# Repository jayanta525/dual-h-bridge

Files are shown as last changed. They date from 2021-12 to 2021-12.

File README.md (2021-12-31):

### Personal Project

2021

# Dual H Bridge Controller with N-CH MOSFETS

- IRF3205 N Channel MOSFET
- IR2104 MOSFET Driver
- ATMega328P-AU PWM Generator

#### Made for Dual 250W Brushed wheelchair motor
#### Schematics: https://jayanta525.gitlab.io/dual-h-bridge/sch/
#### Schematics: https://jayanta525.github.io/dual-h-bridge/sch/

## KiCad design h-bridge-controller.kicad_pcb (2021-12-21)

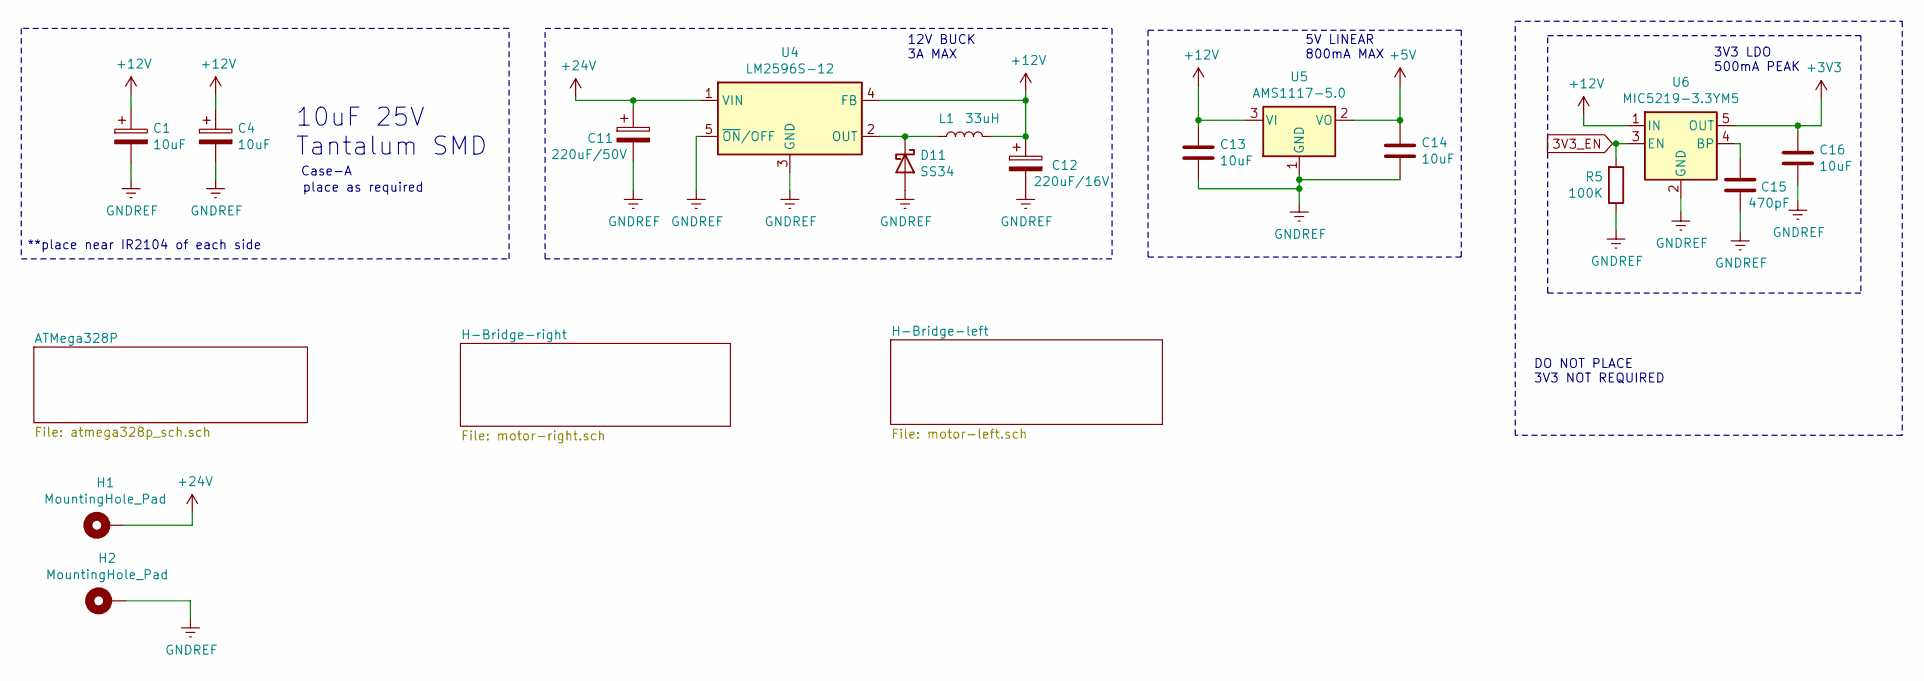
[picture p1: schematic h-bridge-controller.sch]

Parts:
C1, C4: 10uF; CP_EIA-3216-18_Kemet-A
C11: 220uF/50V; CP_Elec_10x10.5
C12: 220uF/16V; CP_Elec_6.3x7.7
C13, C14, C16: 10uF; C_0805_2012Metric
C15: 470pF; C_0805_2012Metric
D11: SS34; D_SMA
H1, H2: MountingHole_Pad; MountingHole_2.2mm_M2_Pad_Via
L1: 33uH; L_12x12mm_H4.5mm
R5: 100K; R_0805_2012Metric
U4: LM2596S-12; TO-263-5_TabPin3
U5: AMS1117-5.0; SOT-223-3_TabPin2
U6: MIC5219-3.3YM5; SOT-23-5

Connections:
3V3_EN: R5.2, U6.3 (EN); also elsewhere on the board
+3V3: C16.1, U6.5 (OUT)
+5V: C14.1, U5.2 (VO); also elsewhere on the board
+12V: C1.1, C4.1, C12.1, C13.1, L1.2, U4.4 (FB), U5.3 (VI), U6.1 (IN); also elsewhere on the board
+24V: C11.1, H1.1, U4.1 (VIN); also elsewhere on the board
GNDREF: C1.2, C4.2, C11.2, C12.2, C13.2, C14.2, C15.2, C16.2, D11.2 (A), H2.1, R5.1, U4.3 (GND), U4.5 (~ON~/OFF), U5.1 (GND), U6.2 (GND); also elsewhere on the board
unnamed: C15.1, U6.4 (BP)
unnamed: D11.1 (K), L1.1, U4.2 (OUT)

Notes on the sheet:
10uF 25V Tantalum SMD
Case-A
place as required
12V BUCK 3A MAX
5V LINEAR 800mA MAX
3V3 LDO 500mA PEAK
**place near IR2104 of each side
DO NOT PLACE 3V3 NOT REQUIRED

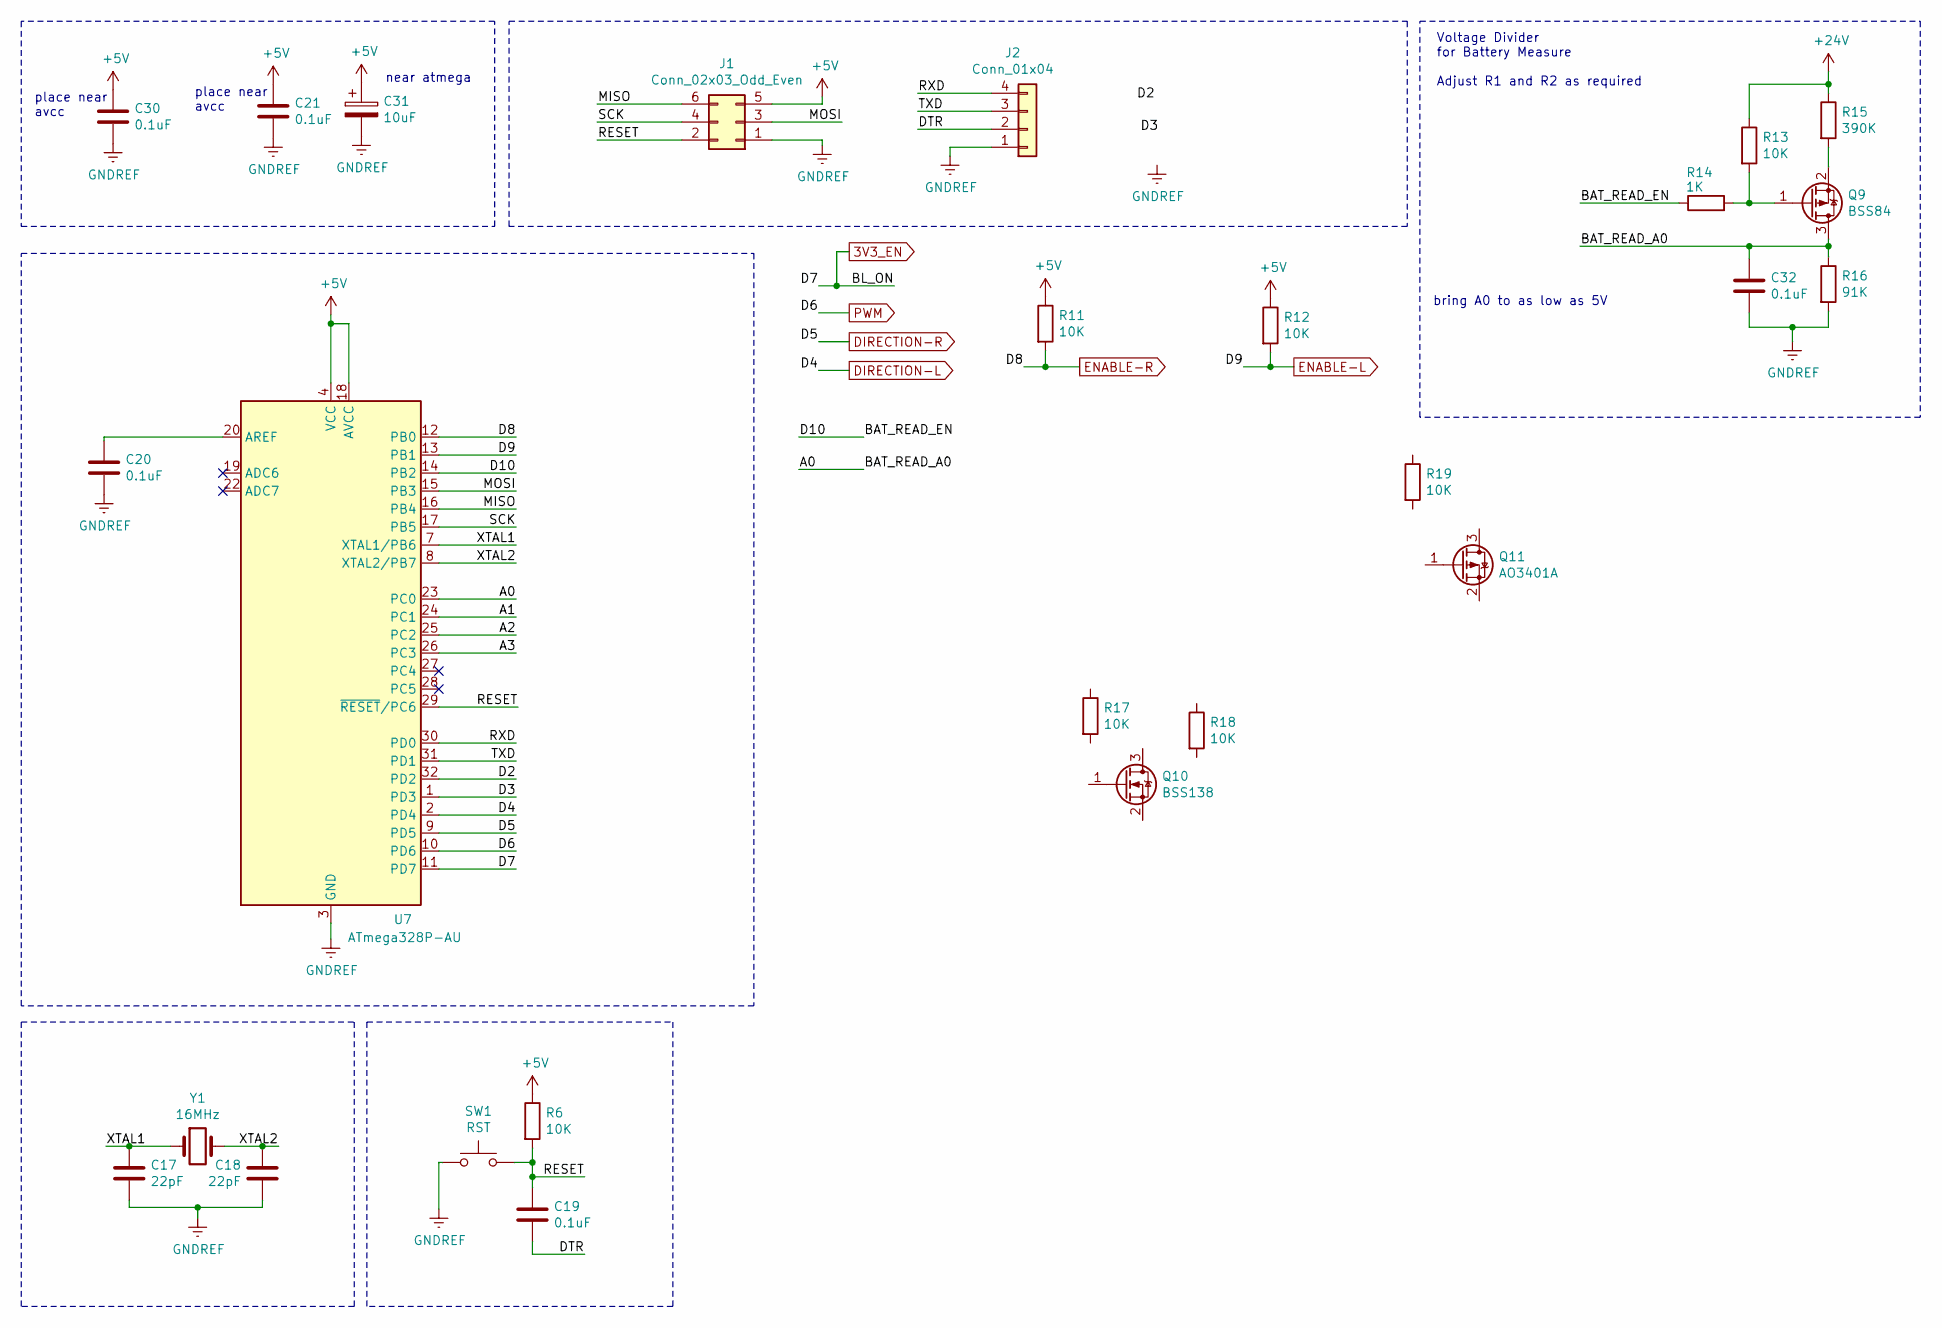
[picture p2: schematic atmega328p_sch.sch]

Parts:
C17, C18: 22pF; C_0805_2012Metric
C19, C20, C21, C30, C32: 0.1uF; C_0805_2012Metric
C31: 10uF; CP_EIA-3216-18_Kemet-A
J1: Conn_02x03_Odd_Even; PinHeader_2x03_P2.54mm_Vertical
J2: Conn_01x04; PinHeader_1x04_P2.54mm_Vertical
Q9: BSS84; SOT-23
Q10: BSS138; SOT-23
Q11: AO3401A; SOT-23
R6, R11, R12, R13, R17, R18, R19: 10K; R_0805_2012Metric
R14: 1K; R_0805_2012Metric
R15: 390K; R_0805_2012Metric
R16: 91K; R_0805_2012Metric
SW1: RST; SW_SPST_TL3342
U7: ATmega328P-AU; TQFP-32_7x7mm_P0.8mm
Y1: 16MHz; Crystal_SMD_HC49-SD

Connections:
3V3_EN: U7.11 (PD7); also elsewhere on the board
+5V: C21.1, C30.1, C31.1, J1.5, R6.1, R11.1, R12.1, U7.4 (VCC), U7.6 (VCC), U7.18 (AVCC); also elsewhere on the board
+24V: R13.1, R15.1; also elsewhere on the board
/ATMega328P/A0: C32.1, Q9.3 (D), R16.1, U7.23 (PC0)
/ATMega328P/A1: U7.24 (PC1)
/ATMega328P/A2: U7.25 (PC2)
/ATMega328P/A3: U7.26 (PC3)
/ATMega328P/BAT_READ_EN: R14.1, U7.14 (PB2)
/ATMega328P/D2: U7.32 (PD2)
/ATMega328P/D3: U7.1 (PD3)
/ATMega328P/DTR: C19.2, J2.2
/ATMega328P/MISO: J1.6, U7.16 (PB4)
/ATMega328P/MOSI: J1.3, U7.15 (PB3)
/ATMega328P/RESET: C19.1, J1.2, R6.2, SW1.2, U7.29 (~RESET~/PC6)
/ATMega328P/RXD: J2.4, U7.30 (PD0)
/ATMega328P/SCK: J1.4, U7.17 (PB5)
/ATMega328P/TXD: J2.3, U7.31 (PD1)
/ATMega328P/XTAL1: C17.1, U7.7 (XTAL1/PB6), Y1.1
/ATMega328P/XTAL2: C18.1, U7.8 (XTAL2/PB7), Y1.2
DIRECTION-L: U7.2 (PD4); also elsewhere on the board
DIRECTION-R: U7.9 (PD5); also elsewhere on the board
ENABLE-L: R12.2, U7.13 (PB1); also elsewhere on the board
ENABLE-R: R11.2, U7.12 (PB0); also elsewhere on the board
GNDREF: C17.2, C18.2, C20.2, C21.2, C30.2, C31.2, C32.2, J1.1, J2.1, R16.2, SW1.1, U7.3 (GND), U7.5 (GND), U7.21 (GND); also elsewhere on the board
unnamed: C20.1, U7.20 (AREF)
unnamed: Q9.1 (G), R13.2, R14.2
unnamed: Q9.2 (S), R15.2
PWM: U7.10 (PD6); also elsewhere on the board

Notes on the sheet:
place near avcc
near atmega
Voltage Divider for Battery Measure Adjust R1 and R2 as required
bring A0 to as low as 5V

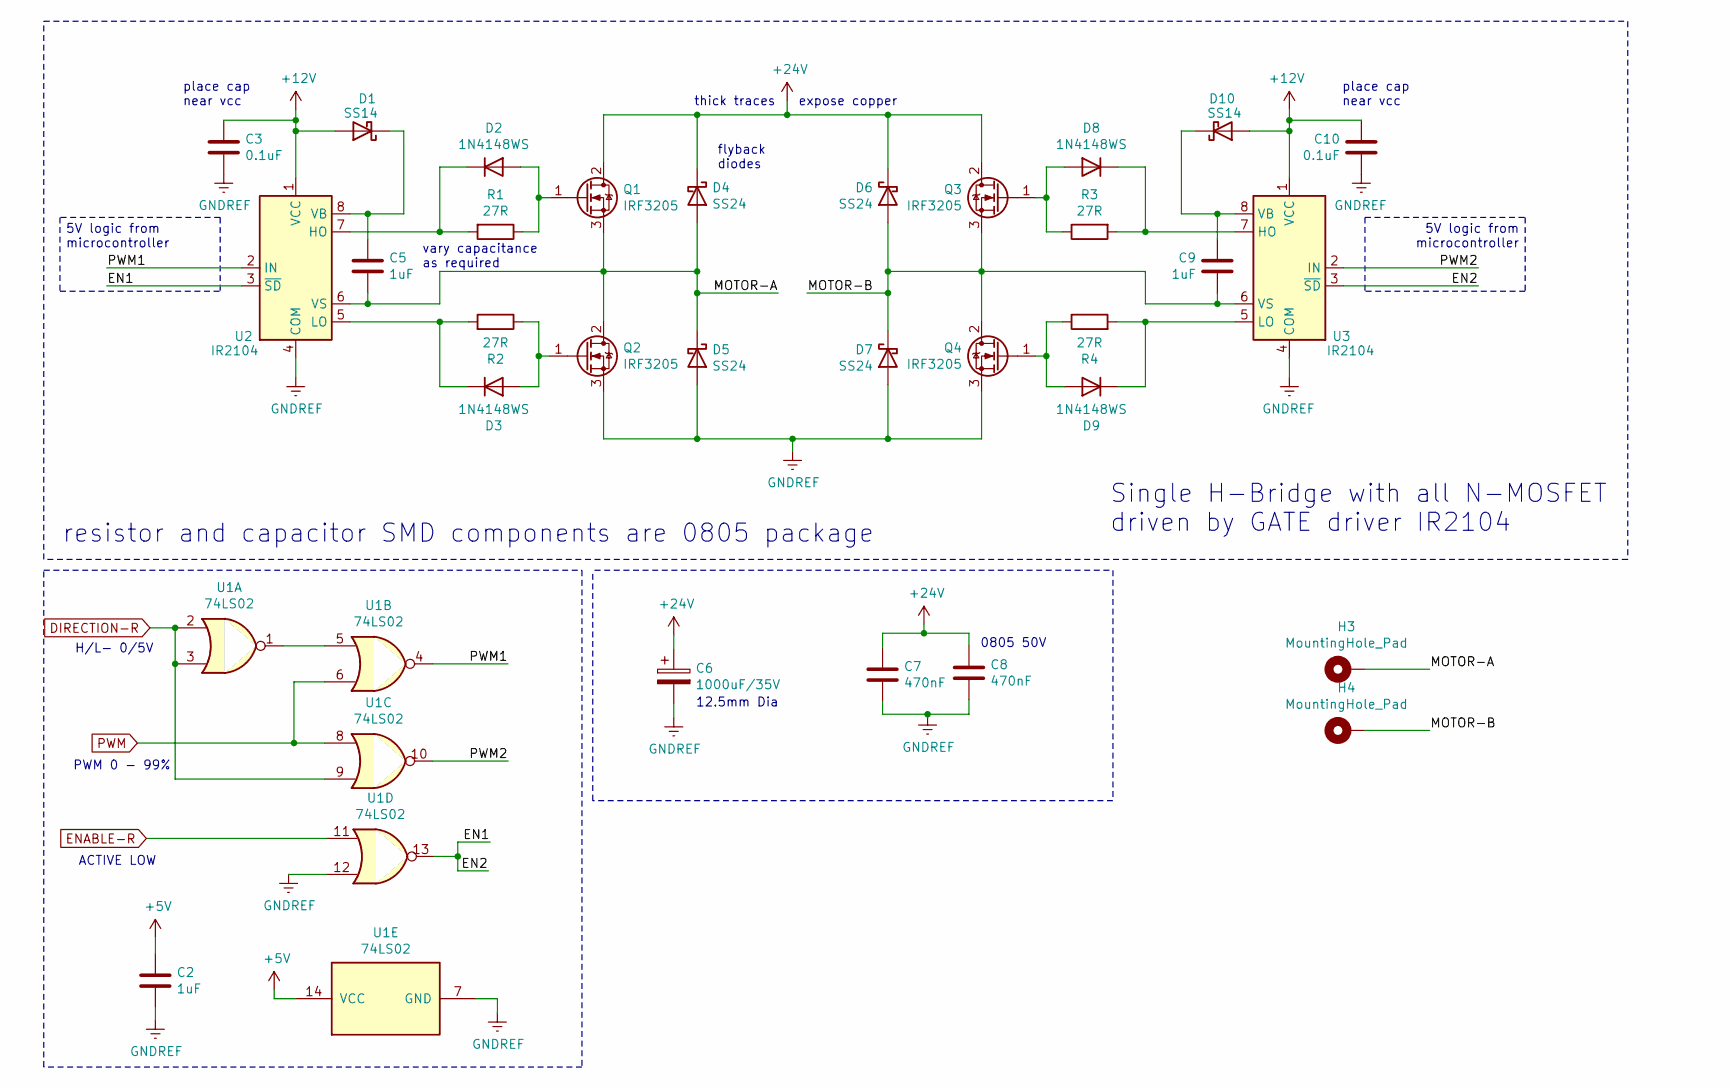
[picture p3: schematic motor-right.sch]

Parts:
C2, C5, C9: 1uF; C_0805_2012Metric
C3, C10: 0.1uF; C_0805_2012Metric
C6: 1000uF/35V; CP_Radial_D12.5mm_P5.00mm
C7, C8: 470nF; C_0805_2012Metric
D1, D10: SS14; D_SMA
D2, D3, D8, D9: 1N4148WS; D_SOD-323
D4, D5, D6, D7: SS24; D_SMA
H3, H4: MountingHole_Pad; MountingHole_2.2mm_M2_Pad_Via
Q1, Q2, Q3, Q4: IRF3205; TO-220-3_Vertical
R1, R2, R3, R4: 27R; R_0805_2012Metric
U1: 74LS02; SOIC-14_3.9x8.7mm_P1.27mm
U2, U3: IR2104; SOIC-8_3.9x4.9mm_P1.27mm

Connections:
+5V: C2.1, U1.14 (VCC); also elsewhere on the board
+12V: C3.1, C10.1, D1.2 (A), D10.2 (A), U2.1 (VCC), U3.1 (VCC); also elsewhere on the board
+24V: C6.1, C7.1, C8.1, D4.1 (K), D6.1 (K), Q1.2 (D), Q3.2 (D); also elsewhere on the board
/H-Bridge-right/EN1: U1.13, U2.3 (~SD), U3.3 (~SD)
/H-Bridge-right/MOTOR-A: C5.2, D4.2 (A), D5.1 (K), H3.1, Q1.3 (S), Q2.2 (D), U2.6 (VS)
/H-Bridge-right/MOTOR-B: C9.2, D6.2 (A), D7.1 (K), H4.1, Q3.3 (S), Q4.2 (D), U3.6 (VS)
/H-Bridge-right/PWM1: U1.4, U2.2 (IN)
/H-Bridge-right/PWM2: U1.10, U3.2 (IN)
DIRECTION-R: U1.2, U1.3, U1.9; also elsewhere on the board
ENABLE-R: U1.11; also elsewhere on the board
GNDREF: C2.2, C3.2, C6.2, C7.2, C8.2, C10.2, D5.2 (A), D7.2 (A), Q2.3 (S), Q4.3 (S), U1.7 (GND), U1.12, U2.4 (COM), U3.4 (COM); also elsewhere on the board
unnamed: C5.1, D1.1 (K), U2.8 (VB)
unnamed: C9.1, D10.1 (K), U3.8 (VB)
unnamed: D2.1 (K), R1.2, U2.7 (HO)
unnamed: D2.2 (A), Q1.1 (G), R1.1
unnamed: D3.1 (K), R2.2, U2.5 (LO)
unnamed: D3.2 (A), Q2.1 (G), R2.1
unnamed: D8.1 (K), R3.2, U3.7 (HO)
unnamed: D8.2 (A), Q3.1 (G), R3.1
unnamed: D9.1 (K), R4.2, U3.5 (LO)
unnamed: D9.2 (A), Q4.1 (G), R4.1
unnamed: U1.1, U1.5
PWM: U1.6, U1.8; also elsewhere on the board

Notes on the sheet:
place cap near vcc
vary capacitance as required
resistor and capacitor SMD components are 0805 package
thick traces
expose copper
5V logic from microcontroller
H/L- 0/5V
PWM 0 - 99%
ACTIVE LOW
flyback diodes
Single H-Bridge with all N-MOSFET driven by GATE driver IR2104
12.5mm Dia
0805 50V

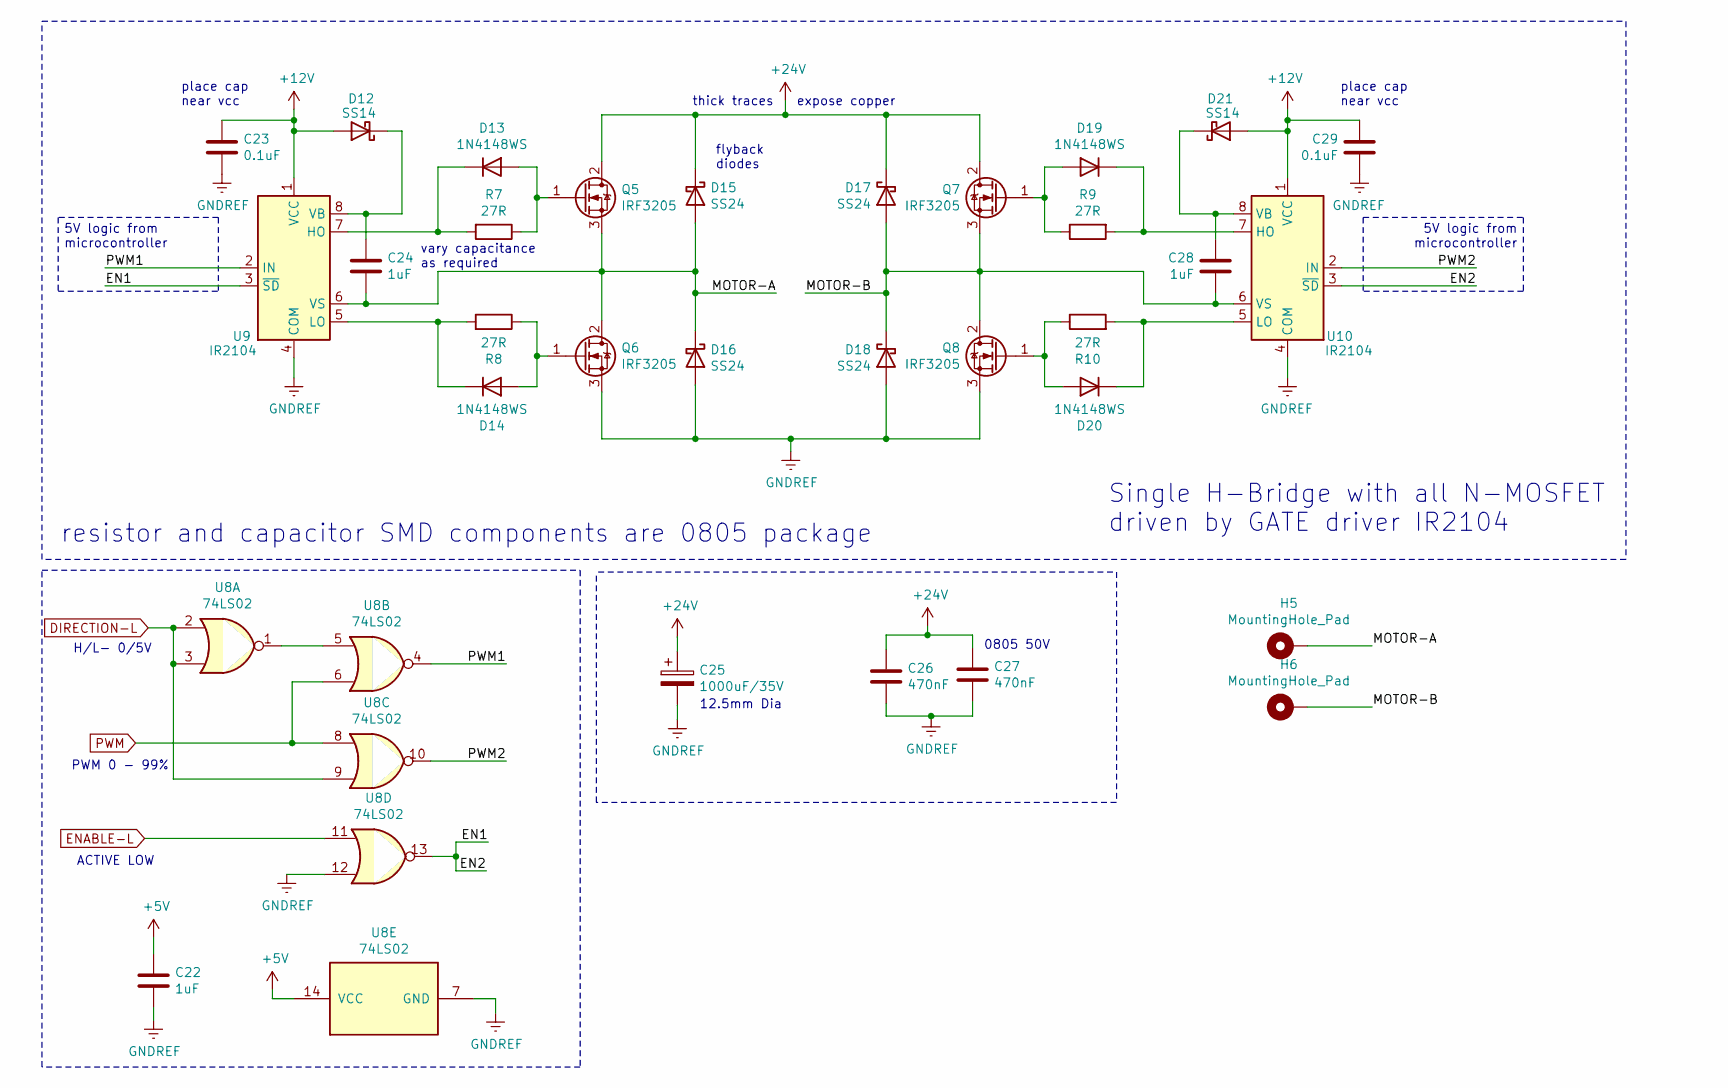
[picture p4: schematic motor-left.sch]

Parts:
C22, C24, C28: 1uF; C_0805_2012Metric
C23, C29: 0.1uF; C_0805_2012Metric
C25: 1000uF/35V; CP_Radial_D12.5mm_P5.00mm
C26, C27: 470nF; C_0805_2012Metric
D12, D21: SS14; D_SMA
D13, D14, D19, D20: 1N4148WS; D_SOD-323
D15, D16, D17, D18: SS24; D_SMA
H5, H6: MountingHole_Pad; MountingHole_2.2mm_M2_Pad_Via
Q5, Q6, Q7, Q8: IRF3205; TO-220-3_Vertical
R7, R8, R9, R10: 27R; R_0805_2012Metric
U8: 74LS02; SOIC-14_3.9x8.7mm_P1.27mm
U9, U10: IR2104; SOIC-8_3.9x4.9mm_P1.27mm

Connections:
+5V: C22.1, U8.14 (VCC); also elsewhere on the board
+12V: C23.1, C29.1, D12.2 (A), D21.2 (A), U9.1 (VCC), U10.1 (VCC); also elsewhere on the board
+24V: C25.1, C26.1, C27.1, D15.1 (K), D17.1 (K), Q5.2 (D), Q7.2 (D); also elsewhere on the board
/H-Bridge-left/EN1: U8.13, U9.3 (~SD), U10.3 (~SD)
/H-Bridge-left/MOTOR-A: C24.2, D15.2 (A), D16.1 (K), H5.1, Q5.3 (S), Q6.2 (D), U9.6 (VS)
/H-Bridge-left/MOTOR-B: C28.2, D17.2 (A), D18.1 (K), H6.1, Q7.3 (S), Q8.2 (D), U10.6 (VS)
/H-Bridge-left/PWM1: U8.4, U9.2 (IN)
/H-Bridge-left/PWM2: U8.10, U10.2 (IN)
DIRECTION-L: U8.2, U8.3, U8.9; also elsewhere on the board
ENABLE-L: U8.11; also elsewhere on the board
GNDREF: C22.2, C23.2, C25.2, C26.2, C27.2, C29.2, D16.2 (A), D18.2 (A), Q6.3 (S), Q8.3 (S), U8.7 (GND), U8.12, U9.4 (COM), U10.4 (COM); also elsewhere on the board
unnamed: C24.1, D12.1 (K), U9.8 (VB)
unnamed: C28.1, D21.1 (K), U10.8 (VB)
unnamed: D13.1 (K), R7.2, U9.7 (HO)
unnamed: D13.2 (A), Q5.1 (G), R7.1
unnamed: D14.1 (K), R8.2, U9.5 (LO)
unnamed: D14.2 (A), Q6.1 (G), R8.1
unnamed: D19.1 (K), R9.2, U10.7 (HO)
unnamed: D19.2 (A), Q7.1 (G), R9.1
unnamed: D20.1 (K), R10.2, U10.5 (LO)
unnamed: D20.2 (A), Q8.1 (G), R10.1
unnamed: U8.1, U8.5
PWM: U8.6, U8.8; also elsewhere on the board

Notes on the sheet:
place cap near vcc
vary capacitance as required
resistor and capacitor SMD components are 0805 package
thick traces
expose copper
5V logic from microcontroller
H/L- 0/5V
PWM 0 - 99%
ACTIVE LOW
flyback diodes
Single H-Bridge with all N-MOSFET driven by GATE driver IR2104
12.5mm Dia
0805 50V

Board: 2 copper layers, 104 parts (16 on the bottom side), 59 nets, no tracks yet.

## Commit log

2021-12-21 init project
    [atmega328p_sch.sch, h-bridge-controller.kicad_pcb, h-bridge-controller.sch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]
2021-12-28 update to kicad6<< revert this
    [atmega328p_sch.kicad_sch, h-bridge-controller.kicad_pcb, h-bridge-controller.kicad_sch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]
2022-01-16 Revert "update to kicad6<< revert this"
    This reverts commit 94c354bf1f03422d884be196bd183532f7be4acb.
    [atmega328p_sch.kicad_sch, h-bridge-controller.kicad_pcb, h-bridge-controller.kicad_sch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]
